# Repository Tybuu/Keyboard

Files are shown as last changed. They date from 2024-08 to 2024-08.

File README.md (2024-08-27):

# Tybeast Ones HE

 The Tybeast Ones HE is a split hall effect mechanical keyboard heavily
 inspired by the Corne. Written using the Rust Embassy framework.

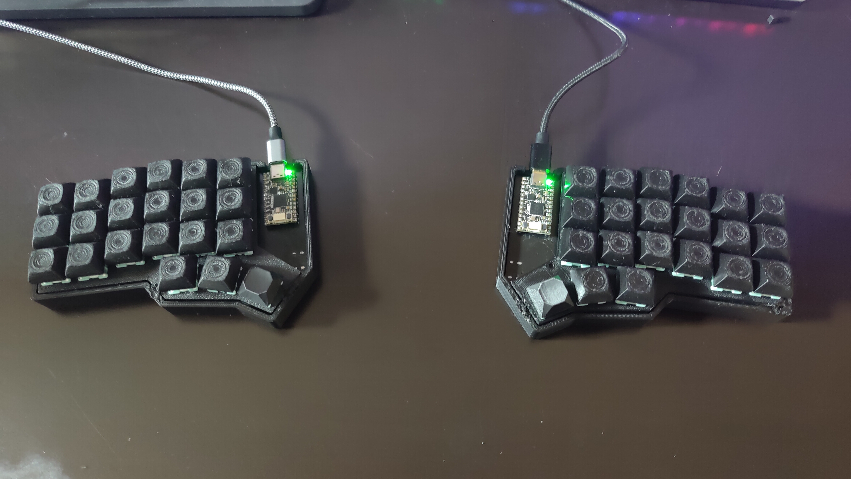
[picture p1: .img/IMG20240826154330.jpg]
Image of the split keyboard


## Loading Firmware

To load the firmware, you'll need to have [elf2uf2-rs](https://github.com/JoNil/elf2uf2-rs).
Once the KB2040 is in bootsel mode, you can use

`cargo run --release --bin <OPTION>`

where OPTION consists of either "left" or "right" depending on which
side you're loading for.

## Making Both Sides Connect

I for the life of me couldn't figure out how to solder a USB-C receptacle onto the PCB
so the firmware will have to use the HID protocol to communicate with
one another rather than using something like UART.
This can be done by using [Keyboard-Link](https://github.com/Tybuu/link).

## Components used in PCB

* Linear Hall Effect Sensors: AH49FNTR-G1
* Analog Multiplexers: CD74HC4051M96
* Dev Board: Adafruit KB2040

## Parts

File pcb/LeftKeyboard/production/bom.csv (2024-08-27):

Designator | Footprint | Quantity | Value | LCSC Part #
_6, _5, _4, _3, _2, |  | 6
C17, C18, C19, C20, C21, C22, C23, C24, C25, C26, C27, C28, C29, C30, C31, C32, C33, C34, C35, C36, C37, C38, C39, C40, C41 | 0805 | 25 | 10n
J4 | USB_C_Receptacle_GCT_USB4105-xx-A_16P_TopMnt_Horizontal | 1 | USB_C_Receptacle_USB2.0_16P
U1 | KB2040 | 1 | ~
U10, U11, U12, U13, U14, U15, U16, U17, U18, U19, U20, U21, U22, U23, U24, U25, U26, U27, U28, U29, U9 | SOT-23 | 21 | DRV5055A3xDBZxQ1
U31 | SOT-23-5 | 1 | AT24CS02-STUM
U5, U6, U7, U8 | SOIC-16_3.9x9.9mm_P1.27mm | 4 | 74HC4051

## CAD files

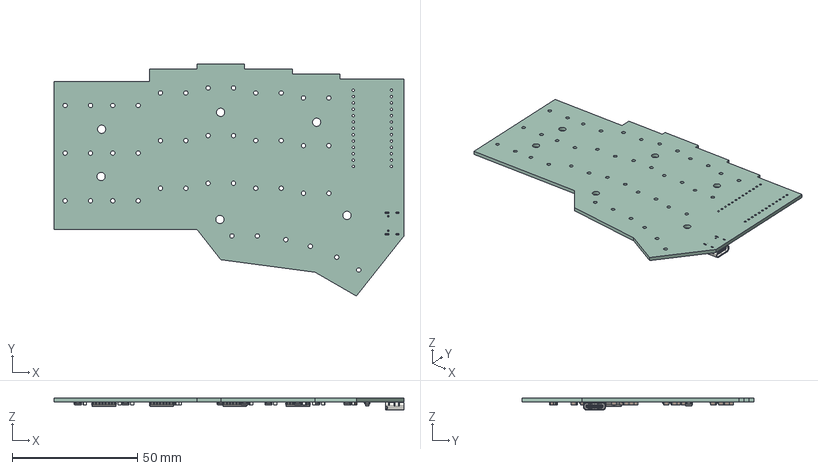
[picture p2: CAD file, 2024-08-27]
pcb/LeftKeyboard/Keyboard.step
139.9 x 92.8 x 4.96 mm
SOT_23 x 21
C_0805_2012Metric x 25
USB_C_Receptacle_16P_TopMnt_Horizontal_GCT_USB4105-xx-A
SOIC_16_39x99mm_P127mm x 4
SOT_23_5
Keyboard_PCB

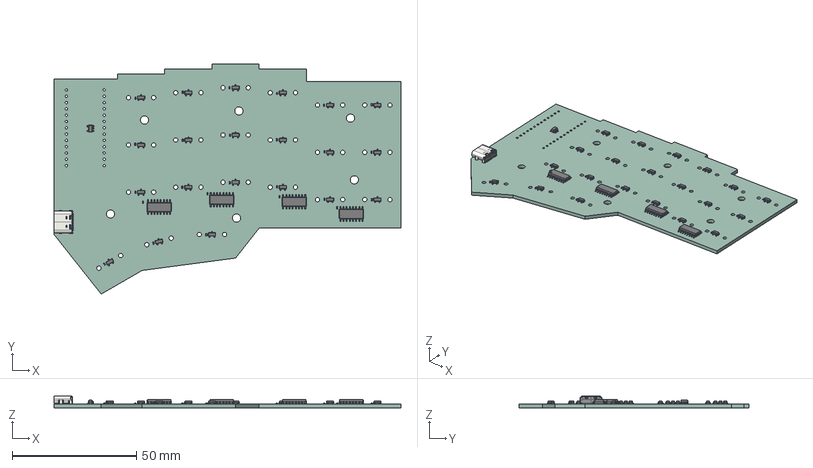
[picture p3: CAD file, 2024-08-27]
pcb/RightKeyboard/Keyboard.step
139.9 x 92.8 x 4.96 mm
SOT_23 x 21
C_0402_1005Metric x 25
USB_C_Receptacle_16P_TopMnt_Horizontal_GCT_USB4105-xx-A
SOIC_16_39x99mm_P127mm x 4
SOT_23_5
Keyboard_PCB

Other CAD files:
pcb/RightKeyboard/RightKeyboard.step

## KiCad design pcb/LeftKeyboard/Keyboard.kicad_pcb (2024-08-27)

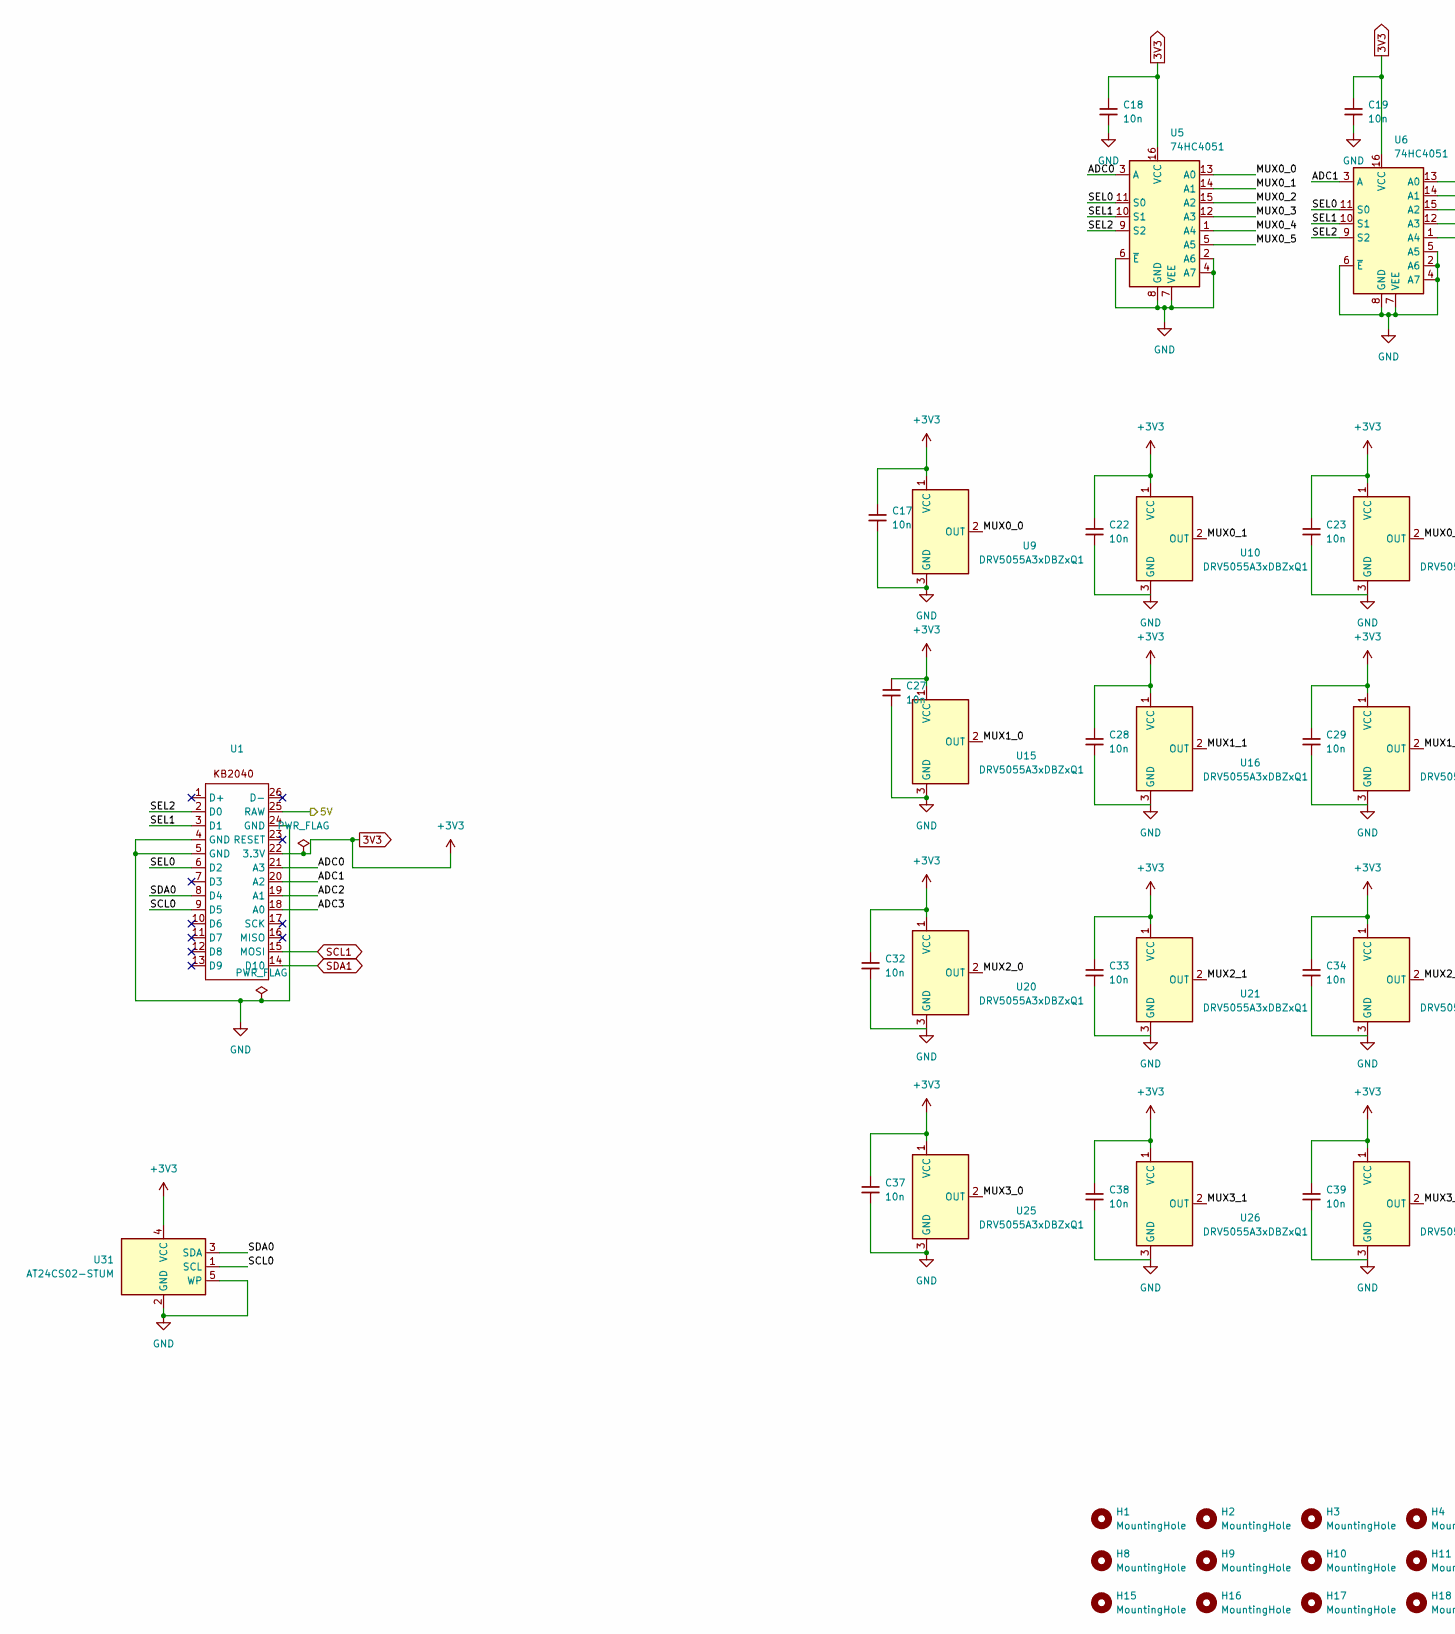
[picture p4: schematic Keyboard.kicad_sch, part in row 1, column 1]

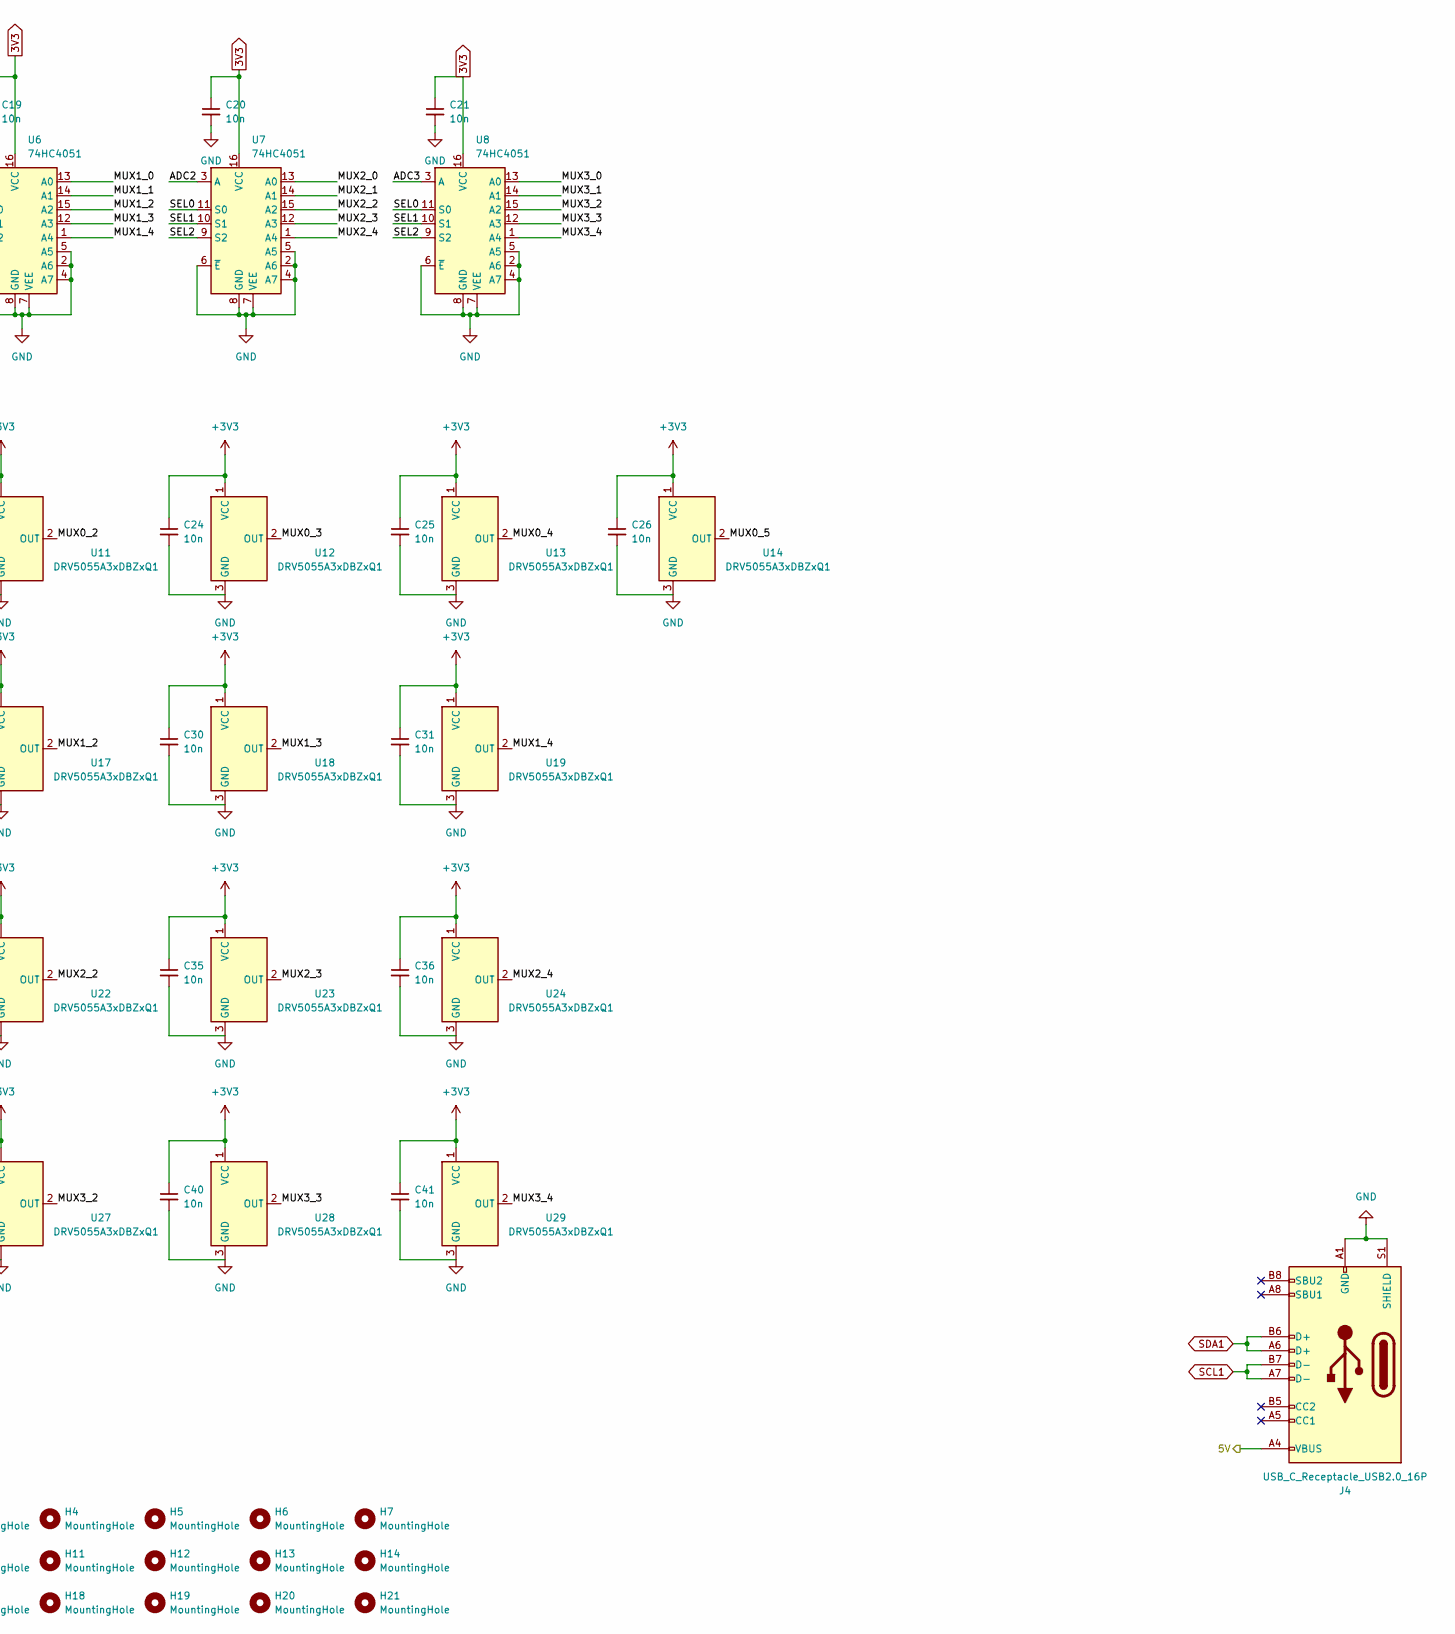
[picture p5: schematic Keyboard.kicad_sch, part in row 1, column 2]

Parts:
C17, C18, C19, C20, C21, C22, C23, C24, C25, C26, C27, C28, C29, C30, C31, C32, C33, C34, C35, C36, C37, C38, C39, C40, C41: 10n; C_0402_1005Metric
H1, H2, H3, H4, H5, H6, H7, H8, H9, H10, H11, H12, H13, H14, H15, H16, H17, H18, H19, H20, H21: MountingHole; switch_holes
J4: USB_C_Receptacle_USB2.0_16P; USB_C_Receptacle_GCT_USB4105-xx-A_16P_TopMnt_Horizontal
U1: KB2040
U5, U6, U7, U8: 74HC4051; SOIC-16_3.9x9.9mm_P1.27mm
U9, U10, U11, U12, U13, U14, U15, U16, U17, U18, U19, U20, U21, U22, U23, U24, U25, U26, U27, U28, U29: DRV5055A3xDBZxQ1; SOT-23
U31: AT24CS02-STUM; SOT-23-5

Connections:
3V3: C17.1, C18.1, C19.1, C20.1, C21.1, C22.1, C23.1, C24.1, C25.1, C26.1, C27.1, C28.1, C29.1, C30.1, C31.1, C32.1, C33.1, C34.1, C35.1, C36.1, C37.1, C38.1, C39.1, C40.1, C41.1, U1.22 (3.3V), U5.16 (VCC), U6.16 (VCC), U7.16 (VCC), U8.16 (VCC), U9.1 (VCC), U10.1 (VCC), U11.1 (VCC), U12.1 (VCC), U13.1 (VCC), U14.1 (VCC), U15.1 (VCC), U16.1 (VCC), U17.1 (VCC), U18.1 (VCC), U19.1 (VCC), U20.1 (VCC), U21.1 (VCC), U22.1 (VCC), U23.1 (VCC), U24.1 (VCC), U25.1 (VCC), U26.1 (VCC), U27.1 (VCC), U28.1 (VCC), U29.1 (VCC), U31.4 (VCC)
/5V: J4.A4 (VBUS), J4.A9 (VBUS), J4.B4 (VBUS), J4.B9 (VBUS), U1.25 (RAW)
/ADC0: U1.21 (A3), U5.3 (A)
/ADC1: U1.20 (A2), U6.3 (A)
/ADC2: U1.19 (A1), U7.3 (A)
/ADC3: U1.18 (A0), U8.3 (A)
/MUX0_0: U5.13 (A0), U9.2 (OUT)
/MUX0_1: U5.14 (A1), U10.2 (OUT)
/MUX0_2: U5.15 (A2), U11.2 (OUT)
/MUX0_3: U5.12 (A3), U12.2 (OUT)
/MUX0_4: U5.1 (A4), U13.2 (OUT)
/MUX0_5: U5.5 (A5), U14.2 (OUT)
/MUX1_0: U6.13 (A0), U15.2 (OUT)
/MUX1_1: U6.14 (A1), U16.2 (OUT)
/MUX1_2: U6.15 (A2), U17.2 (OUT)
/MUX1_3: U6.12 (A3), U18.2 (OUT)
/MUX1_4: U6.1 (A4), U19.2 (OUT)
/MUX2_0: U7.13 (A0), U20.2 (OUT)
/MUX2_1: U7.14 (A1), U21.2 (OUT)
/MUX2_2: U7.15 (A2), U22.2 (OUT)
/MUX2_3: U7.12 (A3), U23.2 (OUT)
/MUX2_4: U7.1 (A4), U24.2 (OUT)
/MUX3_0: U8.13 (A0), U25.2 (OUT)
/MUX3_1: U8.14 (A1), U26.2 (OUT)
/MUX3_2: U8.15 (A2), U27.2 (OUT)
/MUX3_3: U8.12 (A3), U28.2 (OUT)
/MUX3_4: U8.1 (A4), U29.2 (OUT)
/SCL0: U1.9 (D5), U31.1 (SCL)
/SDA0: U1.8 (D4), U31.3 (SDA)
/SEL0: U1.6 (D2), U5.11 (S0), U6.11 (S0), U7.11 (S0), U8.11 (S0)
/SEL1: U1.3 (D1), U5.10 (S1), U6.10 (S1), U7.10 (S1), U8.10 (S1)
/SEL2: U1.2 (D0), U5.9 (S2), U6.9 (S2), U7.9 (S2), U8.9 (S2)
GND: C17.2, C18.2, C19.2, C20.2, C21.2, C22.2, C23.2, C24.2, C25.2, C26.2, C27.2, C28.2, C29.2, C30.2, C31.2, C32.2, C33.2, C34.2, C35.2, C36.2, C37.2, C38.2, C39.2, C40.2, C41.2, J4.A1 (GND), J4.A12 (GND), J4.B1 (GND), J4.B12 (GND), J4.S1 (SHIELD), U1.4 (GND), U1.5 (GND), U1.24 (GND), U5.2 (A6), U5.4 (A7), U5.6 (~E), U5.7 (VEE), U5.8 (GND), U6.2 (A6), U6.4 (A7), U6.5 (A5), U6.6 (~E), U6.7 (VEE), U6.8 (GND), U7.2 (A6), U7.4 (A7), U7.5 (A5), U7.6 (~E), U7.7 (VEE), U7.8 (GND), U8.2 (A6), U8.4 (A7), U8.5 (A5), U8.6 (~E), U8.7 (VEE), U8.8 (GND), U9.3 (GND), U10.3 (GND), U11.3 (GND), U12.3 (GND), U13.3 (GND), U14.3 (GND), U15.3 (GND), U16.3 (GND), U17.3 (GND), U18.3 (GND), U19.3 (GND), U20.3 (GND), U21.3 (GND), U22.3 (GND), U23.3 (GND), U24.3 (GND), U25.3 (GND), U26.3 (GND), U27.3 (GND), U28.3 (GND), U29.3 (GND), U31.2 (GND), U31.5 (WP)
SCL1: J4.A7 (D-), J4.B7 (D-), U1.15 (MOSI)
SDA1: J4.A6 (D+), J4.B6 (D+), U1.14 (D10)

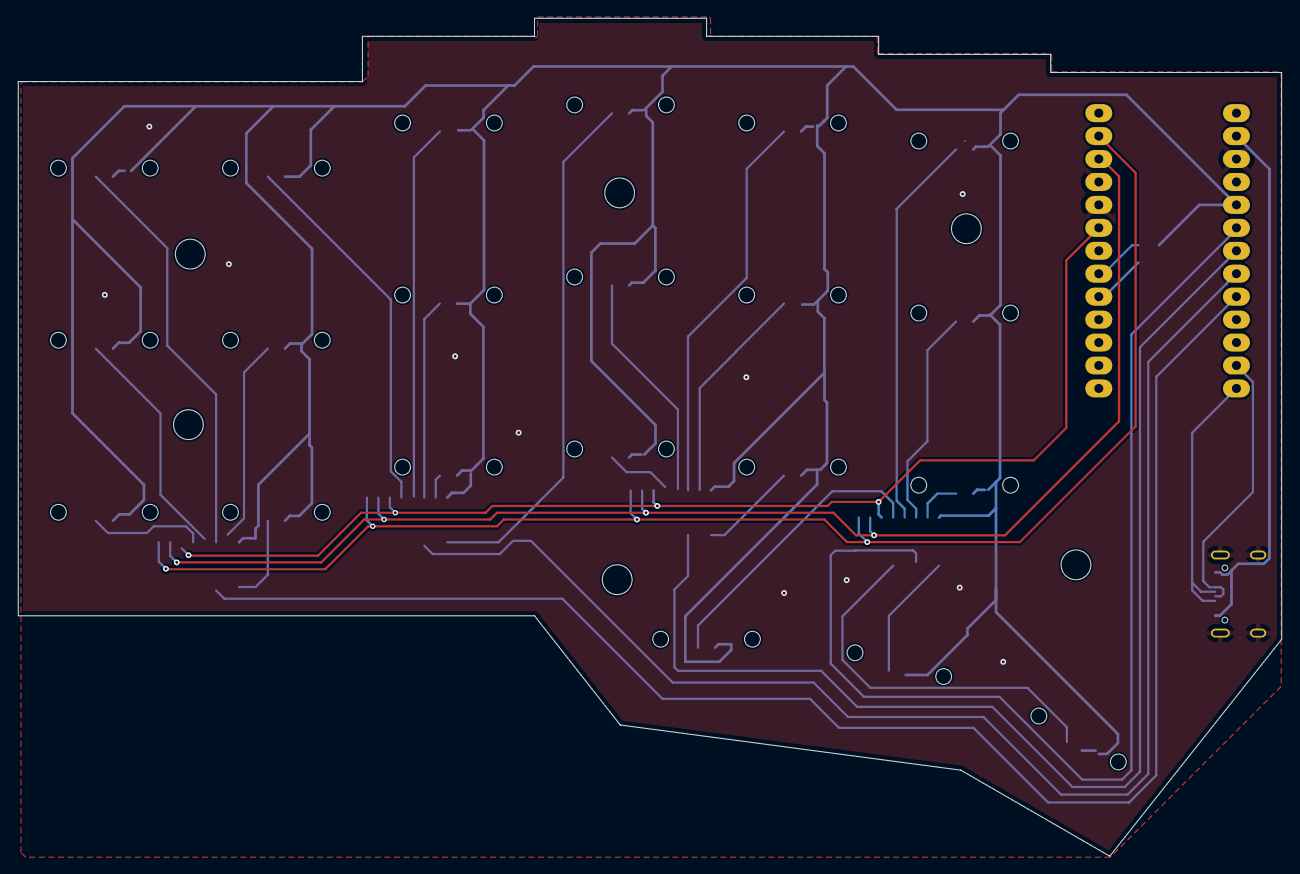
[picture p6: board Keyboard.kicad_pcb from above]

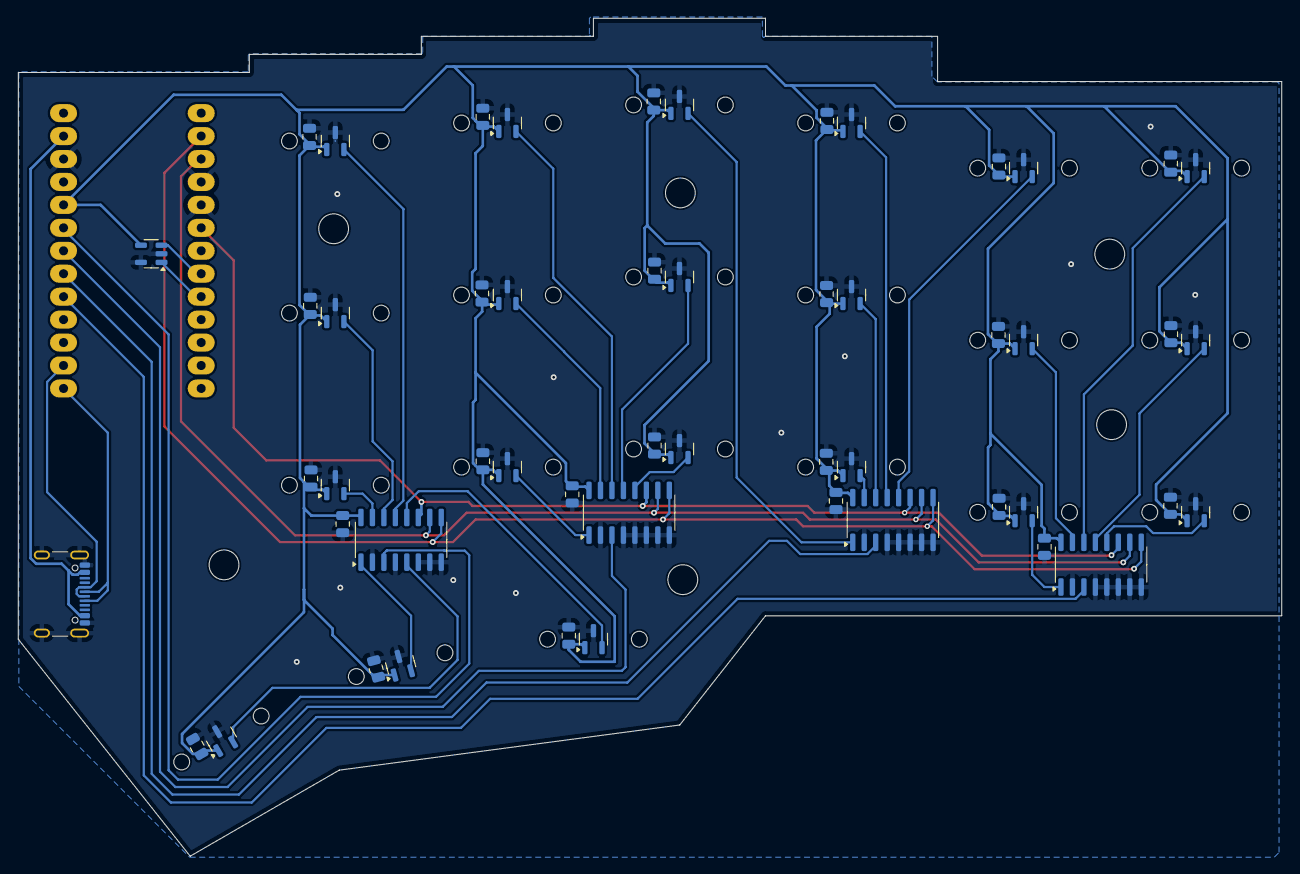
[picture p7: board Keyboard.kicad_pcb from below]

Board: 2 copper layers, 139.9 x 92.8 mm, 74 parts (73 on the bottom side), 35 nets.

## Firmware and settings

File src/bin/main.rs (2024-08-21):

//! This example test the RP Pico on board LED.
//!
//! It does not work with the RP Pico W board. See wifi_blinky.rs.

#![no_std]
#![no_main]

use core::sync::atomic::{AtomicBool, Ordering};

use defmt::info;
use embassy_executor::Spawner;
use embassy_futures::join::{join, join3, join_array};
use embassy_rp::adc::{self, Adc, Channel, Config as AdcConfig};
use embassy_rp::gpio::{Pin, Pull};
use embassy_rp::{bind_interrupts, gpio, peripherals, usb};
use embassy_sync::blocking_mutex::raw::CriticalSectionRawMutex;
use embassy_sync::mutex::Mutex;
use embassy_time::{Duration, Timer};
use keyboard::codes::KeyCodes;
use keyboard::descriptor::{BufferReport, KeyboardReportNKRO, MouseReport};
use keyboard::keys::Keys;

use embassy_rp::usb::Driver;
use embassy_usb::class::hid::{HidReaderWriter, HidWriter, State};
use embassy_usb::{Builder, Config, Handler};
use gpio::{Level, Output};
use keyboard::report::{Report, NUM_KEYS};
use usbd_hid::descriptor::SerializedDescriptor;
use {defmt_rtt as _, panic_probe as _};

bind_interrupts!(struct Irqs {
    USBCTRL_IRQ => usb::InterruptHandler<peripherals::USB>;
    ADC_IRQ_FIFO => adc::InterruptHandler;
});

static MUX: Mutex<CriticalSectionRawMutex, [u8; 3]> = Mutex::new([0u8; 3]);

const SCROLL_TIME: u64 = 500;
const MOUSE_POINTER_TIME: u64 = 10;

#[embassy_executor::main]
async fn main(_spawner: Spawner) {
    info!("Device Started!");
    let p = embassy_rp::init(Default::default());
    // Create the driver, from the HAL.
    let driver = Driver::new(p.USB, Irqs);

    // Create embassy-usb Config
    let mut config = Config::new(0xa55, 0xa55);
    config.manufacturer = Some("Tybeast Corp.");
    config.product = Some("Tybeast Ones (Left)");
    config.max_power = 500;
    config.max_packet_size_0 = 64;
    config.composite_with_iads = true;
    config.device_class = 0xef;
    config.device_sub_class = 0x02;
    config.device_protocol = 0x01;

    // Create embassy-usb DeviceBuilder using the driver and config.
    // It needs some buffers for building the descriptors.
    let mut config_descriptor = [0; 256];
    let mut bos_descriptor = [0; 256];
    let mut msos_descriptor = [0; 256];
    let mut control_buf = [0; 64];
    let mut device_handler = MyDeviceHandler::new();

    let mut key_state = State::new();
    let mut slave_state = State::new();
    let mut com_state = State::new();
    let mut mouse_state = State::new();

    let mut builder = Builder::new(
        driver,
        config,
        &mut config_descriptor,
        &mut bos_descriptor,
        &mut msos_descriptor,
        &mut control_buf,
    );

    builder.handler(&mut device_handler);

    // Create classes on the builder.
    let key_config = embassy_usb::class::hid::Config {
        report_descriptor: KeyboardReportNKRO::desc(),
        request_handler: None,
        poll_ms: 1,
        max_packet_size: 32,
    };
    let slave_config = embassy_usb::class::hid::Config {
        report_descriptor: BufferReport::desc(),
        request_handler: None,
        poll_ms: 1,
        max_packet_size: 64,
    };
    let com_config = embassy_usb::class::hid::Config {
        report_descriptor: BufferReport::desc(),
        request_handler: None,
        poll_ms: 60,
        max_packet_size: 64,
    };
    let mouse_config = embassy_usb::class::hid::Config {
        report_descriptor: MouseReport::desc(),
        request_handler: None,
        poll_ms: 1,
        max_packet_size: 5,
    };

    let mut key_writer = HidWriter::<_, 29>::new(&mut builder, &mut key_state, key_config);
    let slave_hid = HidReaderWriter::<_, 4, 1>::new(&mut builder, &mut slave_state, slave_config);
    let com_hid = HidReaderWriter::<_, 32, 32>::new(&mut builder, &mut com_state, com_config);
    let mut mouse_writer = HidWriter::<_, 5>::new(&mut builder, &mut mouse_state, mouse_config);

    let (mut s_reader, mut s_writer) = slave_hid.split();
    let (mut c_reader, mut c_writer) = com_hid.split();

    // Build the builder.
    let mut usb = builder.build();
    let usb_fut = usb.run();

    // Sel Pins
    let mut sel0 = Output::new(p.PIN_2, Level::Low);
    let mut sel1 = Output::new(p.PIN_1, Level::Low);
    let mut sel2 = Output::new(p.PIN_0, Level::Low);

    // Adc
    let mut adc = Adc::new(p.ADC, Irqs, AdcConfig::default());
    let mut a3 = Channel::new_pin(p.PIN_26, Pull::None);
    let mut a2 = Channel::new_pin(p.PIN_27, Pull::None);
    let mut a1 = Channel::new_pin(p.PIN_28, Pull::None);
    let mut a0 = Channel::new_pin(p.PIN_29, Pull::None);

    let mut order: [usize; NUM_KEYS / 2] = [
        7, 14, 2, 18, 5, 0, 3, 11, 6, 1, 9, 4, 15, 19, 10, 13, 17, 8, 12, 16, 20,
    ];
    find_order(&mut order);

    let mut keys = Keys::<NUM_KEYS>::default();

    // Layer 0
    keys.set_code(KeyCodes::KeyboardEscape, 0, 0);
    keys.set_code(KeyCodes::KeyboardQq, 1, 0);
    keys.set_code(KeyCodes::KeyboardWw, 2, 0);
    keys.set_code(KeyCodes::KeyboardEe, 3, 0);
    keys.set_code(KeyCodes::KeyboardRr, 4, 0);
    keys.set_code(KeyCodes::KeyboardTt, 5, 0);

    keys.set_code(KeyCodes::KeyboardLeftControl, 6, 0);
    keys.set_code(KeyCodes::KeyboardAa, 7, 0);
    keys.set_code(KeyCodes::KeyboardSs, 8, 0);
    keys.set_code(KeyCodes::KeyboardDd, 9, 0);
    keys.set_code(KeyCodes::KeyboardFf, 10, 0);
    keys.set_code(KeyCodes::KeyboardGg, 11, 0);

    keys.set_code(KeyCodes::KeyboardLeftShift, 12, 0);
    keys.set_code(KeyCodes::KeyboardZz, 13, 0);
    keys.set_code(KeyCodes::KeyboardXx, 14, 0);
    keys.set_code(KeyCodes::KeyboardCc, 15, 0);
    keys.set_code(KeyCodes::KeyboardVv, 16, 0);
    keys.set_code(KeyCodes::KeyboardBb, 17, 0);

    keys.set_code(KeyCodes::KeyboardLeftGUI, 18, 0);
    keys.set_combined(KeyCodes::Layer1, KeyCodes::Layer6, 40, 19, 0);
    keys.set_code(KeyCodes::KeyboardSpacebar, 20, 0);

    keys.set_code(KeyCodes::KeyboardYy, 21, 0);
    keys.set_code(KeyCodes::KeyboardUu, 22, 0);
    keys.set_code(KeyCodes::KeyboardIi, 23, 0);
    keys.set_code(KeyCodes::KeyboardOo, 24, 0);
    keys.set_code(KeyCodes::KeyboardPp, 25, 0);
    keys.set_code(KeyCodes::KeyboardBackspace, 26, 0);

    keys.set_code(KeyCodes::KeyboardHh, 27, 0);
    keys.set_code(KeyCodes::KeyboardJj, 28, 0);
    keys.set_code(KeyCodes::KeyboardKk, 29, 0);
    keys.set_code(KeyCodes::KeyboardLl, 30, 0);
    keys.set_code(KeyCodes::KeyboardSemiColon, 31, 0);
    keys.set_code(KeyCodes::KeyboardSingleDoubleQuote, 32, 0);

    keys.set_code(KeyCodes::KeyboardNn, 33, 0);
    keys.set_code(KeyCodes::KeyboardMm, 34, 0);
    keys.set_code(KeyCodes::KeyboardCommaLess, 35, 0);
    keys.set_code(KeyCodes::KeyboardPeriodGreater, 36, 0);
    keys.set_code(KeyCodes::KeyboardSlashQuestion, 37, 0);
    keys.set_code(KeyCodes::KeyboardRightShift, 38, 0);

    keys.set_code(KeyCodes::KeyboardEnter, 39, 0);
    keys.set_combined(KeyCodes::Layer2, KeyCodes::Layer6, 19, 40, 0);
    keys.set_code(KeyCodes::KeyboardLeftAlt, 41, 0);

    // Layer 1
    keys.set_code(KeyCodes::KeyboardTab, 0, 1);
    keys.set_code(KeyCodes::KeyboardBacktickTilde, 1, 1);
    keys.set_double(
        KeyCodes::KeyboardOpenBracketBrace,
        KeyCodes::KeyboardLeftShift,
        1,
        1,
    );

    keys.set_code(KeyCodes::KeyboardLeftControl, 6, 1);
    keys.set_code(KeyCodes::Keyboard1Exclamation, 7, 1);
    keys.set_code(KeyCodes::Keyboard2At, 8, 1);
    keys.set_code(KeyCodes::Keyboard3Hash, 9, 1);
    keys.set_code(KeyCodes::Keyboard4Dollar, 10, 1);
    keys.set_code(KeyCodes::Keyboard5Percent, 11, 1);

    keys.set_code(KeyCodes::KeyboardLeftShift, 12, 1);

    keys.set_code(KeyCodes::KeyboardLeftGUI, 18, 1);
    keys.set_combined(KeyCodes::Layer1, KeyCodes::Layer6, 40, 19, 1);
    keys.set_code(KeyCodes::KeyboardSpacebar, 20, 1);

    keys.set_code(KeyCodes::KeyboardDashUnderscore, 21, 1);
    keys.set_code(KeyCodes::KeyboardEqualPlus, 22, 1);
    keys.set_code(KeyCodes::KeyboardOpenBracketBrace, 23, 1);
    keys.set_code(KeyCodes::KeyboardCloseBracketBrace, 24, 1);
    keys.set_code(KeyCodes::KeyboardBackslashBar, 25, 1);
    keys.set_code(KeyCodes::KeyboardBackspace, 26, 1);

    keys.set_code(KeyCodes::Keyboard6Caret, 27, 1);
    keys.set_code(KeyCodes::Keyboard7Ampersand, 28, 1);
    keys.set_code(KeyCodes::Keyboard8Asterisk, 29, 1);
    keys.set_code(KeyCodes::Keyboard9OpenParens, 30, 1);
    keys.set_code(KeyCodes::Keyboard0CloseParens, 31, 1);

    keys.set_combined(KeyCodes::Layer2, KeyCodes::Layer6, 19, 40, 1);

    // Layer 2
    keys.set_code(KeyCodes::KeyboardF1, 1, 2);
    keys.set_code(KeyCodes::KeyboardF2, 2, 2);
    keys.set_code(KeyCodes::KeyboardF3, 3, 2);
    keys.set_code(KeyCodes::KeyboardF4, 4, 2);
    keys.set_code(KeyCodes::KeyboardF5, 5, 2);

    keys.set_combined(KeyCodes::Layer1, KeyCodes::Layer6, 40, 19, 2);

    keys.set_code(KeyCodes::KeyboardF6, 21, 2);
    keys.set_code(KeyCodes::KeyboardF7, 22, 2);
    keys.set_code(KeyCodes::KeyboardF8, 23, 2);
    keys.set_code(KeyCodes::KeyboardF9, 24, 2);
    keys.set_code(KeyCodes::KeyboardF10, 25, 2);

    keys.set_code(KeyCodes::KeyboardLeftArrow, 27, 2);
    keys.set_code(KeyCodes::KeyboardDownArrow, 28, 2);
    keys.set_code(KeyCodes::KeyboardUpArrow, 29, 2);
    keys.set_code(KeyCodes::KeyboardRightArrow, 30, 2);

    keys.set_toggle_layer(KeyCodes::Layer3, 38, 2);
    keys.set_combined(KeyCodes::Layer2, KeyCodes::Layer6, 19, 40, 2);

    // Layer 3
    keys.set_code(KeyCodes::KeyboardEscape, 0, 3);
    keys.set_code(KeyCodes::KeyboardQq, 1, 3);
    keys.set_code(KeyCodes::KeyboardWw, 2, 3);
    keys.set_code(KeyCodes::KeyboardEe, 3, 3);
    keys.set_code(KeyCodes::KeyboardRr, 4, 3);
    keys.set_code(KeyCodes::KeyboardTt, 5, 3);

    keys.set_code(KeyCodes::KeyboardLeftControl, 6, 3);
    keys.set_code(KeyCodes::KeyboardAa, 7, 3);
    keys.set_code(KeyCodes::KeyboardSs, 8, 3);
    keys.set_code(KeyCodes::KeyboardDd, 9, 3);
    keys.set_code(KeyCodes::KeyboardFf, 10, 3);
    keys.set_code(KeyCodes::KeyboardGg, 11, 3);

    keys.set_code(KeyCodes::KeyboardLeftShift, 12, 3);
    keys.set_code(KeyCodes::KeyboardZz, 13, 3);
    keys.set_code(KeyCodes::KeyboardXx, 14, 3);
    keys.set_code(KeyCodes::KeyboardCc, 15, 3);
    keys.set_code(KeyCodes::KeyboardVv, 16, 3);
    keys.set_code(KeyCodes::KeyboardBb, 17, 3);

    keys.set_code(KeyCodes::KeyboardLeftGUI, 18, 3);
    keys.set_code(KeyCodes::Layer4, 19, 3);
    keys.set_code(KeyCodes::KeyboardSpacebar, 20, 3);

    let func = |x: u64| -> u64 { ((10000 * x.pow(2)) / (x.pow(2) + 50000)) + 1000 };
    keys.set_interval(
        KeyCodes::MouseScrollUp,
        Duration::from_millis(SCROLL_TIME),
        func,
        21,
        3,
    );
    keys.set_interval(
        KeyCodes::MouseNegativeY,
        Duration::from_millis(MOUSE_POINTER_TIME),
        func,
        23,
        3,
    );

    keys.set_interval(
        KeyCodes::MouseScrollDown,
        Duration::from_millis(SCROLL_TIME),
        func,
        27,
        3,
    );
    keys.set_interval(
        KeyCodes::MouseNegativeX,
        Duration::from_millis(MOUSE_POINTER_TIME),
        func,
        28,
        3,
    );
    keys.set_interval(
        KeyCodes::MousePositiveY,
        Duration::from_millis(MOUSE_POINTER_TIME),
        func,
        29,
        3,
    );
    keys.set_interval(
        KeyCodes::MousePositiveX,
        Duration::from_millis(MOUSE_POINTER_TIME),
        func,
        30,
        3,
    );

    keys.set_code(KeyCodes::MouseLeftClick, 39, 3);
    keys.set_code(KeyCodes::MouseRightClick, 40, 3);

    // Layer 4
    keys.set_code(KeyCodes::KeyboardLeftControl, 6, 4);
    keys.set_code(KeyCodes::Keyboard1Exclamation, 7, 4);
    keys.set_code(KeyCodes::Keyboard2At, 8, 4);
    keys.set_code(KeyCodes::Keyboard3Hash, 9, 4);
    keys.set_code(KeyCodes::Keyboard4Dollar, 10, 4);
    keys.set_code(KeyCodes::Keyboard5Percent, 11, 4);

    keys.set_interval(
        KeyCodes::MouseScrollUp,
        Duration::from_millis(SCROLL_TIME),
        func,
        21,
        4,
    );
    keys.set_interval(
        KeyCodes::MouseNegativeY,
        Duration::from_millis(MOUSE_POINTER_TIME),
        func,
        23,
        4,
    );

    keys.set_interval(
        KeyCodes::MouseScrollDown,
        Duration::from_millis(SCROLL_TIME),
        func,
        27,
        4,
    );
    keys.set_interval(
        KeyCodes::MouseNegativeX,
        Duration::from_millis(MOUSE_POINTER_TIME),
        func,
        28,
        4,
    );
    keys.set_interval(
        KeyCodes::MousePositiveY,
        Duration::from_millis(SCROLL_TIME),
        func,
        29,
        4,
    );
    keys.set_interval(
        KeyCodes::MousePositiveX,
        Duration::from_millis(MOUSE_POINTER_TIME),
        func,
        30,
        4,
    );
    keys.set_code(KeyCodes::MouseMiddleClick, 31, 4);

    keys.set_toggle_layer(KeyCodes::Layer0, 38, 4);
    keys.set_code(KeyCodes::MouseLeftClick, 39, 4);
    keys.set_code(KeyCodes::MouseRightClick, 40, 4);

    keys.set_code(KeyCodes::KeyboardAa, 0, 6);
    keys.set_slave(21..42);

    let mut report = Report::default();

    // Main keyboard loop
    let usb_key_in = async {
        loop {
            let mut slave_keys = [0u8; 3];
            {
                let shared = MUX.lock().await;
                slave_keys = *shared;
            }
            let mut pos = 0;
            // Left Keyboard Scan
            for i in order {
                let chan = pos % 4;
                if chan == 0 {
                    change_sel(&mut sel0, &mut sel1, &mut sel2, pos / 4);
                    Timer::after_micros(2).await;
                }
                match chan {
                    0 => keys.update_buf(i, adc.read(&mut a0).await.unwrap()),
                    1 => keys.update_buf(i, adc.read(&mut a1).await.unwrap()),
                    2 => keys.update_buf(i, adc.read(&mut a2).await.unwrap()),
                    3 => keys.update_buf(i, adc.read(&mut a3).await.unwrap()),
                    _ => {}
                }
                pos += 1;
            }
            // Right Keyboard Scan
            for i in 0..21 {
                let a_idx = (i / 8) as usize;
                let b_idx = i % 8;
                let val = (slave_keys[a_idx] >> b_idx) & 1;
                keys.update_buf(i + 21, val as u16);
            }
            let (key_report, m_report) = report.generate_report(&mut keys);
            match key_report {
                Some(report) => {
                    key_writer.write_serialize(&report).await.unwrap();
                }
                None => {}
            }
            match m_report {
                Some(report) => {
                    mouse_writer.write_serialize(&report).await.unwrap();
                }
                None => {}
            }
        }
    };

    let buffer_out = async {
        loop {
            let mut buf = [0u8; 32];
            s_reader.read(&mut buf).await.unwrap();
            if buf[0] == 5 {
                let mut shared = MUX.lock().await;
                (*shared)[0] = buf[1];
                (*shared)[1] = buf[2];
                (*shared)[2] = buf[3];
            }
        }
    };

    join3(usb_key_in, usb_fut, buffer_out).await;
}

struct MyDeviceHandler {
    configured: AtomicBool,
}

impl MyDeviceHandler {
    fn new() -> Self {
        MyDeviceHandler {
            configured: AtomicBool::new(false),
        }
    }
}

impl Handler for MyDeviceHandler {
    fn enabled(&mut self, enabled: bool) {
        self.configured.store(false, Ordering::Relaxed);
        if enabled {
            info!("Device enabled");
        } else {
            info!("Device disabled");
        }
    }

    fn reset(&mut self) {
        self.configured.store(false, Ordering::Relaxed);
        info!("Bus reset, the Vbus current limit is 100mA");
    }

    fn addressed(&mut self, addr: u8) {
        self.configured.store(false, Ordering::Relaxed);
        info!("USB address set to: {}", addr);
    }

    fn configured(&mut self, configured: bool) {
        self.configured.store(configured, Ordering::Relaxed);
        if configured {
            info!(
                "Device configured, it may now draw up to the configured current limit from Vbus."
            )
        } else {
            info!("Device is no longer configured, the Vbus current limit is 100mA.");
        }
    }
}

fn find_order(ary: &mut [usize]) {
    let mut new_ary = [0usize; 21 as usize];
    for i in 0..ary.len() {
        for j in 0..ary.len() {
            if ary[j as usize] == i {
                new_ary[i as usize] = j;
            }
        }
    }
    ary.copy_from_slice(&new_ary);
}

fn change_sel<P0: Pin, P1: Pin, P2: Pin>(
    sel0: &mut Output<P0>,
    sel1: &mut Output<P1>,
    sel2: &mut Output<P2>,
    num: u8,
) {
    match num {
        0 => {
            sel0.set_low();
            sel1.set_low();
            sel2.set_low();
        }
        1 => {
            sel0.set_high();
            sel1.set_low();
            sel2.set_low();
        }
        2 => {
            sel0.set_low();
            sel1.set_high();
            sel2.set_low();
        }
        3 => {
            sel0.set_high();
            sel1.set_high();
            sel2.set_low();
        }
        4 => {
            sel0.set_low();
            sel1.set_low();
            sel2.set_high();
        }
        5 => {
            sel0.set_high();
            sel1.set_low();
            sel2.set_high();
        }
        _ => {
            sel0.set_low();
            sel1.set_low();
            sel2.set_low();
        }
    }
}

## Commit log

2024-08-21 Switched to Embassy framework
2024-08-27 Added pcb files and readme
    [Keyboard-B_Courtyard.gbr, Keyboard-B_Cu.gbl, Keyboard-B_Fab.gbr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]
